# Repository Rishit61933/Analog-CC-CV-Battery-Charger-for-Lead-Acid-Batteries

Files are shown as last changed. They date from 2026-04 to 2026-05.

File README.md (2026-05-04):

# Analog-CC-CV-Battery-Charger-for-Lead-Acid-Batteries

> A fully analog, microcontroller-free smart battery charger for 12V lead-acid batteries — automatically manages Constant Current, Constant Voltage, and Trickle Charge phases using only op-amps, transistors, and MOSFETs.

**Course:** EE322 — Analog and Mixed Signal Circuits  
**Team Name:** The Semicons  
**Institute:** Indian Institute of Technology Gandhinagar

---

## 📌 Project Overview

This project implements a **low-dropout CC-CV charger** with automatic trickle charge mode — entirely in analog. No microcontrollers, no firmware, no bugs. A **P-channel MOSFET (IRF9540)** acts as the main power-pass element, with analog feedback loops handling all stage transitions automatically.



### Charging Stages

```
[Discharged Battery]
        │
        ▼
┌─────────────────┐
│  Constant       │  ← Bulk charge: fixed current, voltage rising
│  Current (CC)   │
└────────┬────────┘
         │ Vbatt reaches 14.4V
         ▼
┌─────────────────┐
│  Constant       │  ← Voltage held at 14.4V, current tapers
│  Voltage (CV)   │
└────────┬────────┘
         │ Current drops to maintenance level
         ▼
┌─────────────────┐
│  Trickle        │  ← Tiny maintenance current, prevents self-discharge
│  Charge         │
└─────────────────┘
        │
        ▼
 [Fully Charged Battery ]
```

---

## 🔧 System Architecture  

The circuit is divided into **7 functional blocks**:

| S. No. | Block Name |
|---|---|
| 1 | AC to DC Converter |
| 2 | Voltage Reference & Regulation |
| 3 | Constant Current Block |
| 4 | Switching & Output Stage |
| 5 | Battery Simulation & Sensing |
| 6 | Charge Indicator Block |
| 7 | Trickle Charge Indicator Block |
### Block Descriptions

**Block 1 — AC to DC Converter**  
Converts AC mains input to a stable ~15V DC rail using a GBU406 bridge rectifier and a 2200µF filter capacitor.

**Block 2 — Voltage Reference & Regulation**  
Uses a TL431A programmable shunt reference + 2N3904 transistor to monitor battery voltage and prevent overcharging above 14.4V.

**Block 3 — Constant Current Block**  
Limits bulk charging current to a safe preset level using TL431A, 2N3906, and 2N3904 transistors with current-sense feedback.

**Block 4 — Switching & Output Stage**  
The IRF9540 P-channel MOSFET acts as an electronic valve, throttled by control signals from the CC and CV feedback loops.

**Block 5 — Battery Simulation & Sensing**  
A 1Ω high-power shunt resistor (Rlim) senses charging current and feeds back into the CC control block.

**Blocks 6 & 7 — Charge & Trickle Indicators**  
2N7000 N-channel MOSFETs drive LEDs to visually indicate the current charging phase (CC/CV vs. Trickle).

---

## 🔩 Key Components

| Component | Role |
|---|---|
| GBU406 Bridge Rectifier | AC → DC conversion |
| 2200µF Filter Capacitor | Smoothing DC rail |
| TL431A (×2) | Programmable voltage reference (CV + CC control) |
| IRF9540 P-channel MOSFET | Main power-pass element |
| 2N3904 / 2N3906 Transistors | Control logic & feedback |
| 2N7000 N-channel MOSFETs | LED indicator drivers |
| 1Ω High-Power Resistor (Rlim) | Current sensing shunt |
| Indicator LEDs | Charge phase visual feedback |

---

## 🔌 How the Control Loop Works

The CC and CV loops **compete** to control the gate of the main MOSFET:

- **CC loop** (via matched transistor pair in U2): detects excess current → pulls MOSFET gate to throttle power
- **CV loop** (via TL431A + Q1): detects voltage exceeding 14.4V → pulls MOSFET gate to throttle power
- **Whichever limit is hit first takes control** — this is the core of the analog CC-CV switching mechanism

```
         ┌─────────────┐
         │ CC Feedback │──────┐
         │  (U2, Q3)   │      │
         └─────────────┘      ▼
                         [Q3 Base] → [Gate of IRF9540 M1] → Output to Battery
         ┌─────────────┐      ▲
         │ CV Feedback │──────┘
         │ (TL431, Q1) │
         └─────────────┘
```

---

## 🧪 Integration & Testing Plan

1. **AC-DC Block** — Verify stable ~15V DC output
2. **Voltage Reference + CC Block** — Breadboard test with lab supply to dial in setpoints
3. **Switching Stage** — Verify MOSFET gate operation in isolation
4. **CC/CV Integration** — Test with high-power dummy load; confirm stable regulation in both modes
5. **LED Indicators** — Simulate each charging phase; verify correct LEDs light up
6. **Full Battery Test** — Connect to a partially discharged 12V lead-acid battery; verify automatic CC → CV → Trickle transitions

---

## ✅ Advantages Over Alternatives

| Feature | This Design | Simple Trickle Charger | MCU-Based Charger |
|---|---|---|---|
| No firmware bugs | ✅ | ✅ | ❌ |
| Auto CC/CV/Trickle | ✅ | ❌ | ✅ |
| Overcharge protection | ✅ | ❌ | ✅ |
| Low dropout design | ✅ | ❌ | Varies |
| Fast charging | ✅ | ❌ | ✅ |
| Low complexity | ✅ | ✅ | ❌ |
| Temp stable (matched pairs) | ✅ | ❌ | ❌ |

---

## 🔮 Future Work

- Temperature-compensated charging curves for better battery longevity
- Adjustable reference to support 6V / 24V lead-acid batteries
- Add analog current/voltage meter readout
- Solar panel input integration (original planned scope)

---

## 📚 References

1. [A Low Dropout CC-CV 12V Lead Acid Battery Charger — EE World Online](https://www.eeworldonline.com/a-low-dropout-cc-cv-12v-lead-acid-battery-charger-with-auto-trickle-charge/)
2. [Lead Acid Battery Charger Reference Design — Texas Instruments SLVA576A](https://www.ti.com/lit/an/slva576a/slva576a.pdf)

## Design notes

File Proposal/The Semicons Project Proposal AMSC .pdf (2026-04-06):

## Project Proposal

### EE322: Analog and Mixed Signal Circuits

### Team Name: The Semicons

Team Members:

1. Aryan Lohiya | 24110057
2. Ahir Heer Ritesh | 24110012
3. Rishit Verma | 24110298

## Project Proposal

### Introduction

This project focuses on creating a smart yet simple all-analog battery charger that takes full control of the charging process without needing any complex digital devices. By using only basic analog components like transistors, op amps, and MOSFETs, the charger automatically moves through the key charging stages—constant current, constant voltage, and a gentle trickle charge. This ensures the battery gets charged quickly, safely, and fully without overcharging or damage. The compact and straightforward design promotes a deep understanding of analog control principles and makes the circuit reliable, affordable, and easy to build—perfect for anyone interested in practical analog electronics.

### Project Statement

This project focuses on developing a straightforward analog charger for 12 V lead-acid batteries that automatically manages charging through three essential phases: constant current, constant voltage, and trickle charge.To help users monitor the charging process, visual LED indicators are integrated. The charger features a low-dropout design, which maintains proper voltage regulation even when the input voltage only slightly exceeds the battery voltage, enhancing overall efficiency.

Note

The original plan was to add a Harvest Energy IC to use energy from sources like solar panels. But, combining that with the charger made the whole system too complicated. So, the project was simplified to just focus on making an analog charger that can handle the entire charging process on its own. This simple design is easier to build, understand, and test. It also keeps the charger affordable and dependable.

## Proposed Approach

### Overview

The proposed approach for this problem statement is to build a low-dropout CC-CV (Constant Current - Constant Voltage) charger with trickle charge mode, all controlled by analog feedback system. A P-channel MOSFET acts as the main power-pass element. It will achieve automatic switching between Constant Current and Constant Voltage, and trickle when the battery is charged fully, to prevent any damages. Constant current charging charges the initially discharged battery in bulk. When the voltage reaches its threshold voltage, it will automatically switch to Constant Voltage mode. Finally, once the battery is charged, it will switch to the trickle mode to prevent overcharging and discharging.

### Components and Blocks

Our design circuit is broken down into 7 blocks primarily.

### Full System Diagram (Block Diagram)

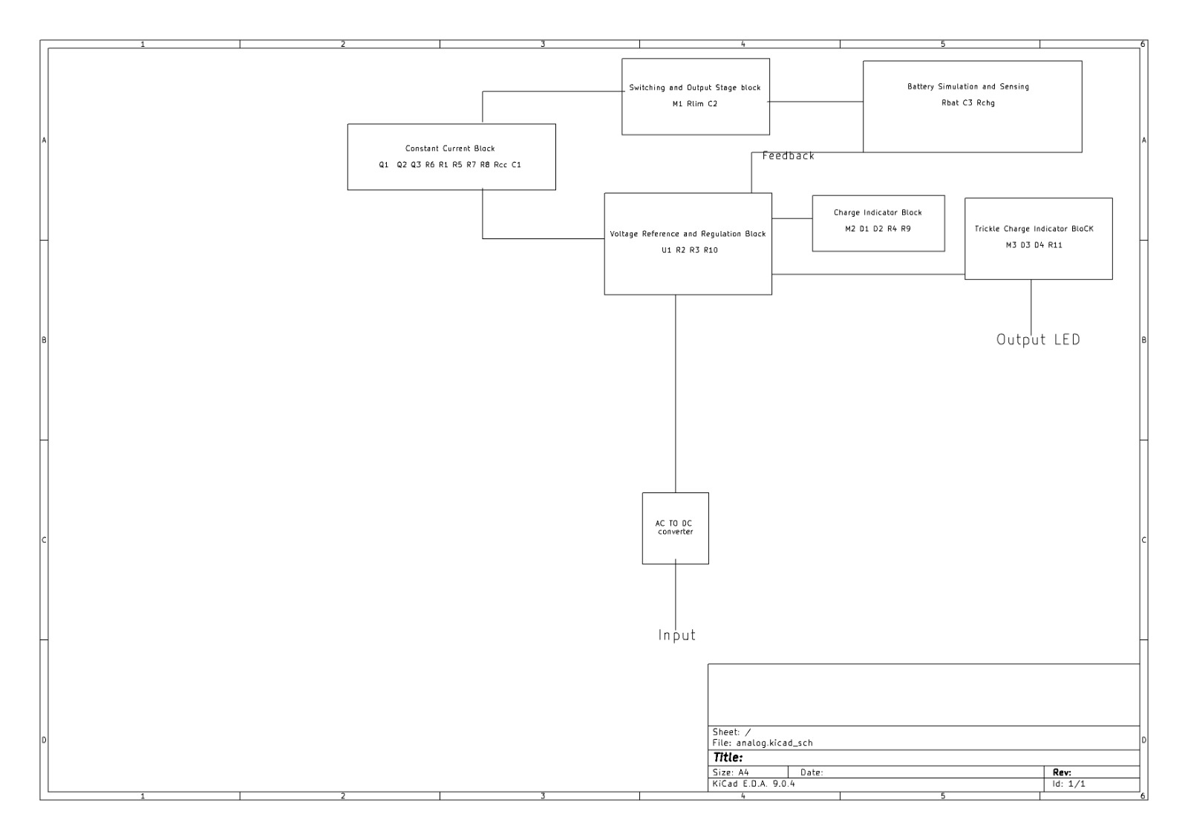
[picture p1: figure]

Figure 1: Full System Block Diagram

## Group PCB Planning

Team Member’s Name | Block No. | Block Name
Rishit Heer Heer Aryan Aryan Rishit Rishit | 1 2 3 4 5 6 7 | AC to DC Generator Voltage Reference and Regulation Block Constant Current Block Switching and Output Stage Block Battery Simulation and Sensing Charge Indicator Block Trickle Charge Indicator Block

### Block Descriptions by Team Member

Rishit’s Blocks (Power Input & User Interface)

Block 1: AC to DC Converter

- Function: Converts input AC voltage to smooth, unregulated DC voltage for the charger.
- Primary Components: GBU406 Bridge Rectifier, 2200µF Filter Capacitor.
- Interaction: Provides main power rail (DC output) to all other blocks.
- Expected Outcome: Stable DC voltage of approximately 15 V for charger operation.

Blocks 6 & 7: Charge & Trickle Charge Indicator Blocks

- Function: Provide visual feedback via LEDs on charger status.
- Primary Components: Indicator LEDs, 2N7000 N-channel MOSFETs.
- Interaction: Receive control signals from logic blocks; act as output indicators.
- Expected Outcome:

– ’Charge Indicator’ LED on during Constant Current and high-current Constant Voltage phases.

– ’Trickle Charge Indicator’ LED on during final maintenance phase.

Heer’s Blocks (Control & Feedback Logic)

Block 2: Voltage Reference and Regulation Block

- Function: Monitors battery voltage to prevent overcharging.
- Primary Components: TL431A Programmable Voltage Reference, 2N3904 transistor.
- Interaction: Senses output voltage; sends control signals to throttle power.
- Expected Outcome: Accurate voltage setpoints maintained and controlled output voltage.

Block 3: Constant Current Block
- Function: Controls bulk charging current to safe preset limits.
- Primary Components: TL431A, 2N3906, 2N3904 transistors.
- Interaction: Receives current sense feedback; sends control signals to limit power.
- Expected Outcome: Charging current limited to desired level during bulk charge phase.

Aryan’s Blocks (Power Switching & Output Stage)

Block 4: Switching and Output Stage Block
- Function: Main MOSFET acting as an electronic valve regulating current flow.
- Primary Components: IRF9540 P-channel MOSFET.
- Interaction: Receives control signals to regulate current to battery.
- Expected Outcome: Efficient current regulation; safe operation with proper heat dissipation.

Block 5: Battery Simulation and Sensing
- Function: Low-ohm shunt resistor for current sensing; connection point for battery.
- Primary Components: 1Ω high-power sense resistor (Rlim).
- Interaction: Senses charging current; feedback to Constant Current block.
- Expected Outcome: Secure battery connection and accurate sensing voltage.

### Plan for Full Integration

Each step should be completed correctly before moving to the next:

1. Test the AC to DC Converter block to verify it provides a stable and correct DC voltage.
2. Test the Voltage Reference and Regulation Block together with the Constant Current Block on a breadboard using a lab power supply to get their setpoints.
3. Perform a basic function test on the Switching and Output Stage Block to ensure the MOSFET is working.
4. Connect the control logic blocks to the Switching and Output Stage Block and conduct initial testing using a high-power dummy load. It should demonstrate stable Constant Current (CC) and Constant Voltage (CV) regulation.
5. Connect the Charge Indicator Block and the Trickle Charge Indicator Block to the control logic and test by simulating different charging phases to ensure the correct LEDs light up for each mode.
6. Connect the fully integrated and tested charger to a partially discharged 12 V lead-acid battery. The charger must automatically transition through all three stages (CC, CV, and Trickle Charge) and bring the battery to full charge.

### Advantages of the Proposed Approach

The proposed all-analog solution offers several significant benefits compared to simple trickle chargers or microcontroller-based systems:

- Highly reliable and free from code bugs.
- Extends battery life by preventing overcharging, gassing, and overheating.
- Matched transistor pairs ensure precision and stability across temperature variations.
- Significantly faster charging than simple trickle chargers.
- Less complex than microcontroller solutions, enhancing accuracy.
- Easy to modify and adapt to specific needs.

## Working of the Circuit

### Basic Circuit Diagram

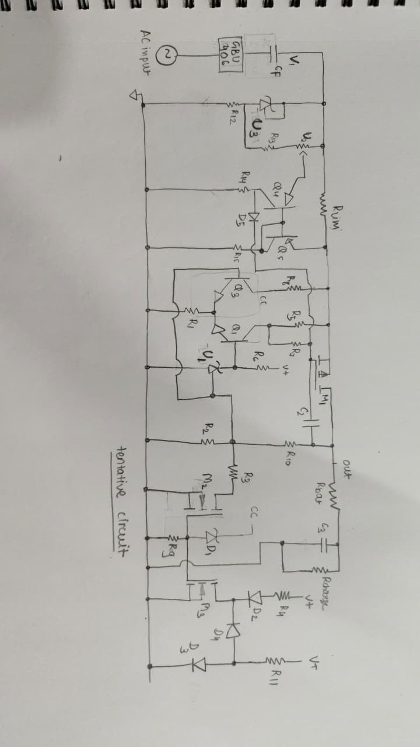
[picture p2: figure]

Figure 2: Basic Circuit Diagram 6

### Step-by-Step Approach

Step 1: To create a stable power source and a precision ruler that the entire circuit will use for accurate measurements.
- Connect the output of AC transformer to the AC pins of the GBU406 rectifier.
- Connect the 2200µF capacitor across the + and - pins of the GBU406. The + pin becomes specific voltage power rail, and the - pin becomes the circuit ground.
- Connect one end of R2 to the specific voltage rail and the other end to the Cathode
(K) pin of U1. Also, connect the Cathode (K) pin to the Reference (REF) pin of U1.
- Connect one end of R3 to the Reference (REF) pin of U1, and the other end to ground. Connect the Anode (A) pin of U1 to ground.
- The circuit is now ”alive.” It has its main DC power source. It has a master reference at the node between R2 and R3. This REF node is the single source of truth for the entire control system.
Step 2: To add the main high-power valve that will control the flow of current to the battery.
- Connect the voltage rail to one terminal of Rtot.
- Connect the wiper of Rtot to one end of Rlim.
- Connect the other end of Rlim to the Source (S) pin of the MOSFET M1.
- Connect the Drain (D) pin of M1 to one end of your dummy load. Connect the other end of the dummy load to ground. This Drain pin is now your main Out node.
- The main power path is complete. However, the M1 valve is currently closed because its gate isn’t connected.
Step 3: To give the circuit the intelligence to watch the output voltage and prevent it from exceeding threshold.
- Connect R13 from the Out node to the Reference (REF) pin of U3.
- Connect R12 from the Reference (REF) pin of U3 to ground.
- Connect the Anode (A) of U3 to ground.
- Connect the Cathode (K) of U3 to one end of R6. Connect the other end of R6 to the Base of Q1.
- Connect the Emitter of Q1 to ground.
- Connect the Collector of Q1 to the control path (we will connect this fully in the next step). For now, connect a 20kΩ resistor (R8) from the DC voltage rail to the Gate (G) of M1. This will hold the MOSFET off.

- The circuit now has its overvoltage protection. The R13/R12 divider constantly tells U3 the output voltage. If it ever exceeds 14.4V, U3 will turn on Q1, which will be used to pull M1’s gate high and throttle the power.
Step 4: To add the ability to measure current and complete the control loop that drives the MOSFET.
- Connect the Emitters of both Q4 and Q5 (inside U2) to the 15V rail.
- Connect the Base of Q4 to the node between Rtot and Rlim.
- Connect the Base of Q5 to the node after Rlim (the Source of M1).
- Connect the Collector of Q5 to the Base of Q3.
- Connect the Emitter of Q3 to ground via R1.
- Crucial Control Connection: Connect the Collector of Q3 to the Gate (G) of the main MOSFET M1. Also connect R8 (from the previous step) from this same point to the 15V rail.
- Now, connect the collector of Q1 (from the CV loop) to the base of Q3 via R5 and R7.
- The circuit is now a fully functional CC/CV trickle charger. The CC loop (U2) and CV loop (Q1) now fight to control Q3. Whichever one needs to limit the output will pull the base of Q3 down, which in turn raises the gate voltage of M1 to throttle the power.
Step 5: To add the LEDs that communicate the charger’s status.
- Connect the Gate of M2 to the collector of Q3 (the CC- node).
- Connect the Source of M2 to ground. Connect the Drain of M2 to the cathode of the Charging LED (D2). Connect the anode of D2 to a current-limiting resistor (R4) and then to a positive voltage source.
- Connect the rest of the indicator logic (M3, D3, etc.) as shown in the schematic. This logic is designed to turn M3 on when M2 is off.
- The charger can now visually communicate its state. The user can see if it’s in the fast-charging CC/CV mode or the final Trickle mode.
Step 6: To confirm the entire system works together as designed with a real-world load.
- Remove the dummy load.
- Carefully connect the Out node to the positive terminal of the battery.
- Connect the circuit ground to the negative terminal of the battery.

## Division of Work

- Aryan Lohiya: Assisted primarily in writing the Introduction and Problem Statement sections of the report, laying the foundation and context for the project.
- Ahir Heer Ritesh: Contributed by drawing the circuit diagrams, conducting component-level research, and supporting the overall research and compilation of the project report.
- Rishit Verma: Took charge of the simulation and PCB schematic design for the circuit. Additionally, he conducted research on the project components and contributed significantly to the report documentation.

## References

- A Low Dropout CC-CV 12V Lead Acid Battery Charger with Auto
Trickle Charge, EE World Online. Available: https://www.eeworldonline.com/a-low-dropout-cc-cv-12v-lead-acid-battery-charger-with-auto-trickle-charge/ (https://www.eeworldonline.com/a-low-dropout-cc-cv-12v-lead-acid-battery-charger-with-auto-trickle-charge/)
- Low Dropout Battery Charger Design Techniques, EE Times. Available: https://www.eetimes.com/low-dropout-battery-charger-design-techniques/
- Lead Acid Battery Charger Reference Design, Texas Instruments. Available: https://www.ti.com/lit/an/slva576a/slva576a.pdf
- Battery Charging Tutorial, Maxim Integrated. Available: https://www.maximintegrated.com/en/design/technical-documents/app-notes/6/6101.html (https://www.maximintegrated.com/en/design/technical-documents/app-notes/6/6101.html)

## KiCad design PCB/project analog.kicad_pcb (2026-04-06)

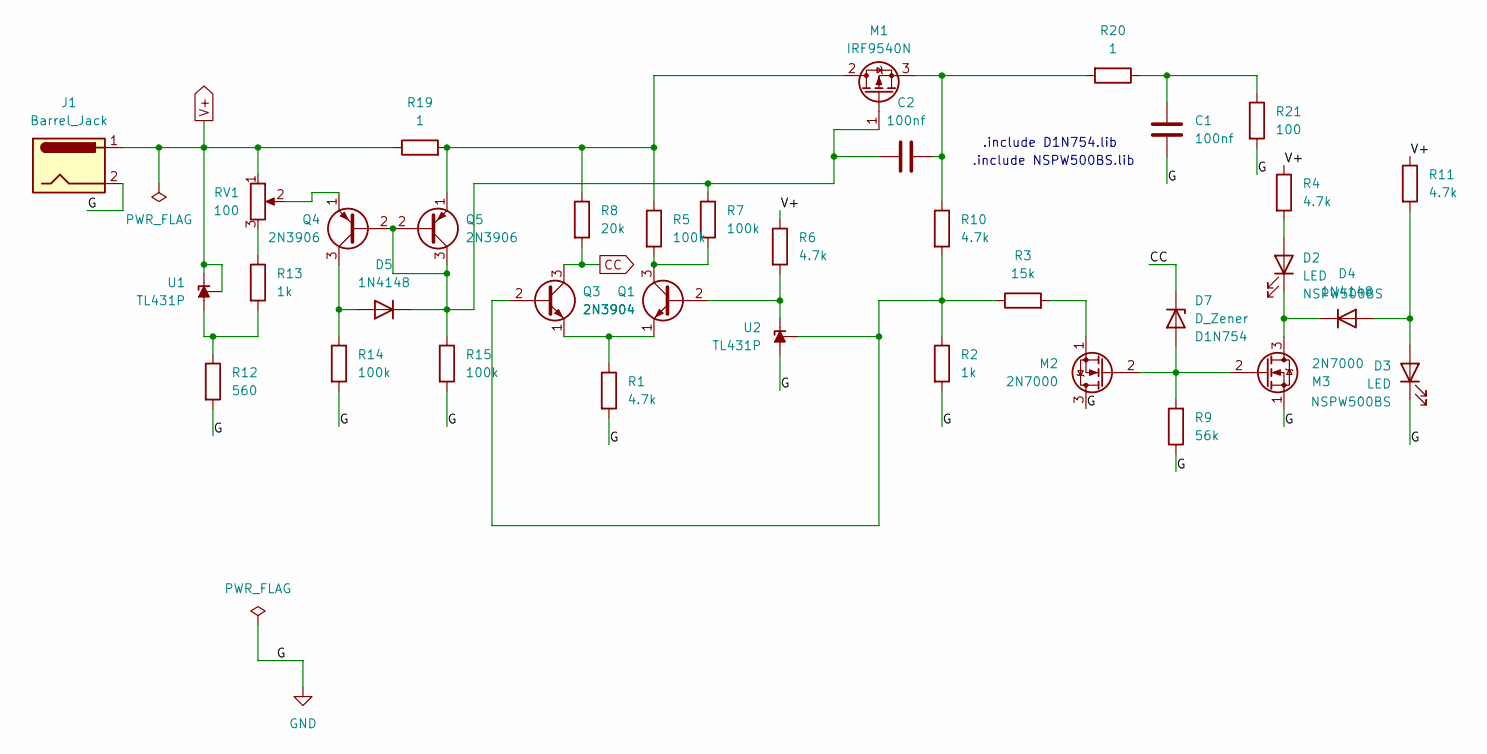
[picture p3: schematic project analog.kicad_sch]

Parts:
C1, C2: 100nf; CP_Radial_D12.5mm_P7.50mm
D2, D3: LED; LED_D5.0mm
D4, D5: 1N4148; D_DO-35_SOD27_P7.62mm_Horizontal
D7: D_Zener; D_DO-35_SOD27_P7.62mm_Horizontal
J1: Barrel_Jack; BarrelJack_Horizontal
M1: IRF9540N; TO-220-3_Vertical
M2, M3: 2N7000; TO-92_Inline
Q1, Q3: 2N3904; TO-92_Inline
Q4, Q5: 2N3906; TO-92_Inline
R1, R4, R6, R10, R11: 4.7k; R_Axial_DIN0309_L9.0mm_D3.2mm_P12.70mm_Horizontal
R2, R13: 1k; R_Axial_DIN0309_L9.0mm_D3.2mm_P12.70mm_Horizontal
R3: 15k; R_Axial_DIN0309_L9.0mm_D3.2mm_P12.70mm_Horizontal
R5, R7, R14, R15: 100k; R_Axial_DIN0309_L9.0mm_D3.2mm_P12.70mm_Horizontal
R8: 20k; R_Axial_DIN0309_L9.0mm_D3.2mm_P12.70mm_Horizontal
R9: 56k; R_Axial_DIN0309_L9.0mm_D3.2mm_P12.70mm_Horizontal
R12: 560; R_Axial_DIN0309_L9.0mm_D3.2mm_P12.70mm_Horizontal
R19, R20: 1; R_Axial_DIN0309_L9.0mm_D3.2mm_P12.70mm_Horizontal
R21: 100; R_Axial_DIN0309_L9.0mm_D3.2mm_P12.70mm_Horizontal
RV1: 100; Potentiometer_Bourns_3296W_Vertical
U1, U2: TL431P; DIP-8_W7.62mm

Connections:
CC: D7.1 (K), Q3.3 (C), R8.2
GND: C1.2, D3.1 (K), J1.2, M2.3 (D), M3.1 (S), R1.2, R2.2, R9.1, R12.2, R14.2, R15.2, R21.2, U2.6 (A)
unnamed: C1.1, R20.1, R21.1
unnamed: D2.2 (A), R4.2
unnamed: D2.1 (K), D4.1 (K), M3.3 (D)
unnamed: D3.2 (A), D4.2 (A), R11.2
unnamed: D5.2 (A), Q4.3 (C), R14.1
unnamed: C2.2, D5.1 (K), M1.1 (G), Q4.2 (B), Q5.2 (B), Q5.3 (C), R7.1, R15.1
unnamed: D7.2 (A), M2.2 (G), M3.2 (G), R9.2
unnamed: M1.2 (D), Q5.1 (E), R5.1, R8.1, R19.2
unnamed: C2.1, M1.3 (S), R10.1, R20.2
unnamed: M2.1 (S), R3.2
unnamed: Q1.2 (B), R6.2, U2.1 (K)
unnamed: Q1.3 (C), R5.2, R7.2
unnamed: Q1.1 (E), Q3.1 (E), R1.1
unnamed: Q3.2 (B), R2.1, R3.1, R10.2, U2.8 (REF)
unnamed: Q4.1 (E), RV1.2
unnamed: R13.1, RV1.3
unnamed: R12.1, R13.2, U1.6 (A)
V+: J1.1, R4.1, R6.1, R11.1, R19.1, RV1.1, U1.1 (K), U1.8 (REF)

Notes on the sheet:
.include D1N754.lib
.include NSPW500BS.lib

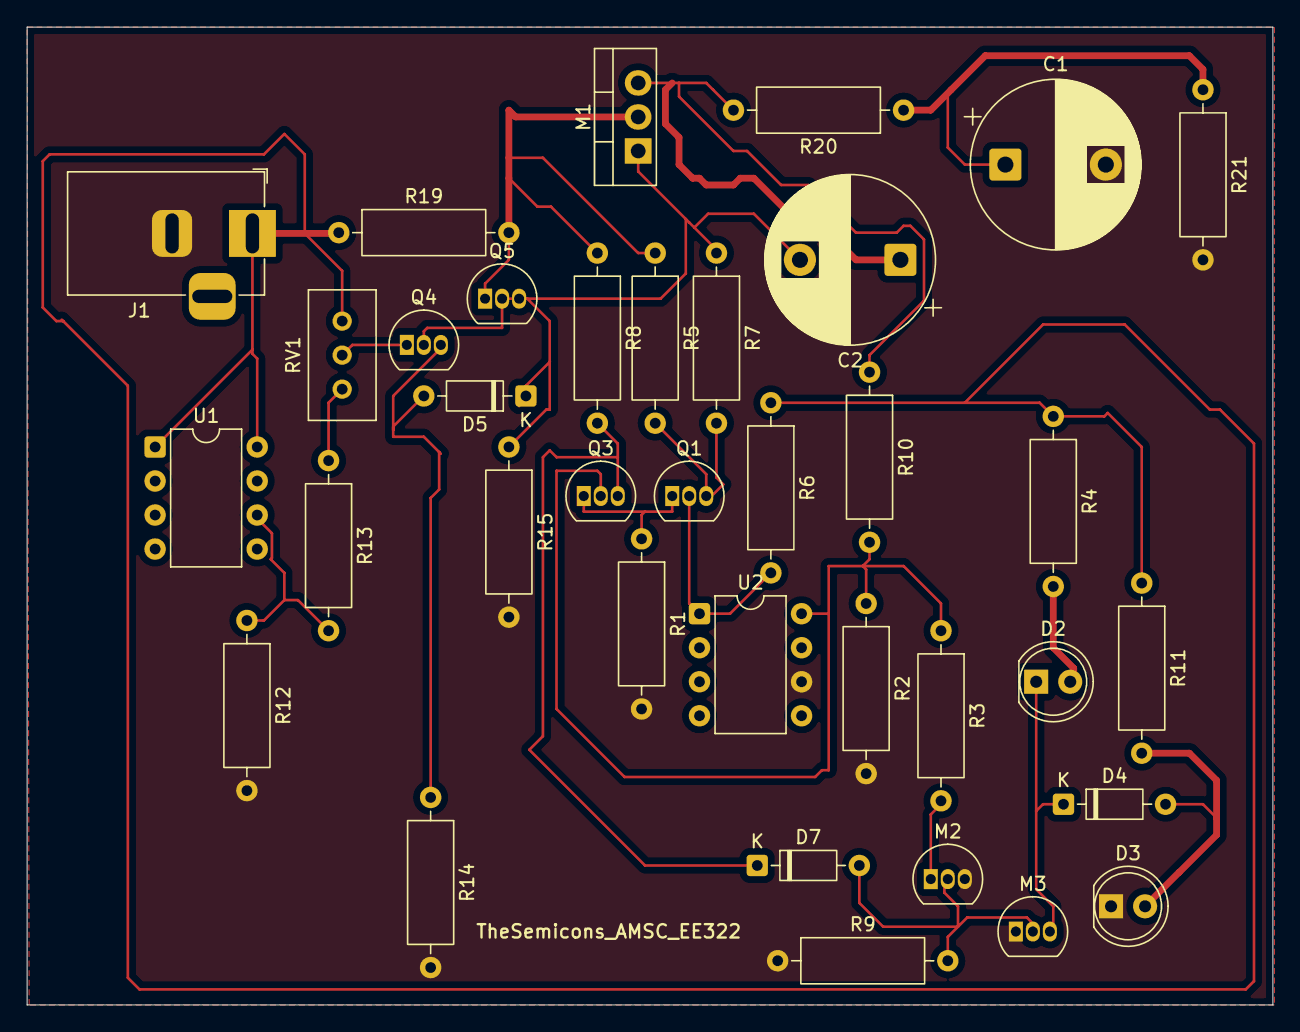
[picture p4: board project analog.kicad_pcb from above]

Board: 2 copper layers, 93.0 x 73.0 mm, 36 parts (0 on the bottom side), 20 nets.

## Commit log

2026-04-06 Rename project analog.kicad_sch to Schematic/project analog.kicad_sch
    [project analog.kicad_sch]
2026-04-06 Rename project analog.kicad_pcb to PCB/project analog.kicad_pcb
    [project analog.kicad_pcb]
2026-04-06 Rename project analog.kicad_pro to PCB/project analog.kicad_pro
